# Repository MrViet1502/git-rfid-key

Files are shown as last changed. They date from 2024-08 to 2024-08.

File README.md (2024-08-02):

## Used devices:
- Arduino pro mini 3v3
- MFRC522 and Cards
- Button config
- Button Power
- Buzzer
- USB UART
  
## Wiring connection diagram

- RED and Black big -> 48V
- White of Button (Pin 6)
- Graay of RESET (Pin reset)
- Blue and white big of Relay 
  ### Load code by USB UART
  - Yellow of TX
  - Green of RX
  - Black small of GND
## Link Demo:
https://youtu.be/RNAoaklGJTw

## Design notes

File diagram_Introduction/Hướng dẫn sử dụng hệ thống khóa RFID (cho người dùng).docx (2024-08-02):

Hướng dẫn sử dụng hệ thống khóa RFID

1. Khởi động hệ thống

Nhấn nút R. Màn hình sáng đèn khoảng 1s. Nếu loa kêu 2 tiếng

2. Bật/tắt điều khiển
- Quét thẻ master hoặc thẻ đã đăng ký (lần 1) để bật.
- Quét thẻ master hoặc thẻ đã đăng ký (lần 2) để tắt, đồng thời tắt hệ thống.
3. Tắt hệ thống
- Nhấn nút R khoảng 2s, loa kêu 2 tiếng
- Khi khởi động mà không làm gì hệ thống sẽ cảnh báo người dùng sau 15s loa kêu hồi chuông 5s và sau 30s loa kêu 2 tiếng
- Khi bật điều khiển mà không làm gì sau 3p, loa kêu 2 tiếng
4. Chế độ cài đặt
- Có thể vào chế độ cài đặt trong vòng 15s sau khi khởi động hệ thống. Dùng để thêm thẻ chưa đăng ký, xóa thẻ đã đăng ký, xóa hết tất cả thẻ (trừ thẻ master).
- Cách vào chế độ cài đặt: nhấn nút R 2 lần. Nếu loa kêu 3 tiếng
- Thêm hoặc xóa thẻ: quét thẻ master. Nếu đúng thẻ loa kêu 2 tiếng. Nếu sai thẻ loa kêu 1 tiếng (tiếp tục quét lại cho đến khi đúng). Tiếp tục quét thẻ nếu là thẻ chưa đăng ký (thẻ mới) loa kêu 1 tiếng và thêm thẻ đó, nếu là thẻ đã đăng ký (thẻ cũ) loa kêu 2 tiếng và xóa thẻ đó.
- Xóa hết: quét thẻ master. Nếu đúng thẻ, loa kêu 2 tiếng. Nếu sai thẻ, loa kêu 1 tiếng (tiếp tục quét lại cho đến khi đúng). Nhấn nút R trong 4s loa kêu 3 tiếng và xóa toàn bộ thẻ (trừ master).

Lưu ý: nếu vào chế động cài đặt mà không làm gì thì sẽ tự kết thúc sau 30s.

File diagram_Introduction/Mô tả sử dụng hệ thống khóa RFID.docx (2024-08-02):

Hướng dẫn sử dụng hệ thống khóa RFID

1. Khởi động hệ thống
- Nhấn nút R. Màn hình sáng đèn khoảng 1s. Nếu loa kêu 2 lần mỗi lần 0.4s.
- Khởi động thành công.
2. Chế độ cài đặt
- Có thể vào chế độ cài đặt trong vòng 15s sau khi khởi động hệ thống. Dùng để thêm thẻ chưa đăng ký, xóa thẻ đã đăng ký, xóa hết tất cả thẻ (trừ thẻ master).
- Cách vào chế độ cài đặt: nhấn nút R 2 lần. Nếu loa kêu 3 lần mỗi lần 0.3s.
- Đã vào chế độ cài đặt.
- Thêm hoặc xóa thẻ: quét thẻ master. Nếu đúng thẻ loa kêu 2 lần mỗi lần 0.3s. Nếu sai thẻ loa kêu 1 lần trong 0.3s (tiếp tục cho đến khi đúng). Tiếp tục quét thẻ nếu là thẻ chưa được thêm (thẻ mới) loa kêu 1 lần trong 0.5s và thêm thẻ đó, nếu là thẻ đã đăng ký (thẻ cũ) loa kêu 2 lần mỗi lần 0.5s và xóa thẻ đó.
- Xóa hết: quét thẻ master. Nếu đúng thẻ loa kêu 2 lần mỗi lần 0.3s. Nếu sai thẻ loa kêu 1 lần trong 0.3s (tiếp tục cho đến khi đúng). Nhấn nút R trong 4s loa kêu 3 lần mỗi lần 0.5s và xóa toàn bộ thẻ (trừ master).

Lưu ý: nếu vào chế động cài đặt mà không làm gì thì sẽ tự kết thúc sau 30s.

3. Bật/tắt điều khiển
- Quét thẻ master hoặc thẻ đã đăng ký (lần 1) để bật.
- Quét thẻ master hoặc thẻ đã đăng ký (lần 2) để tắt, đồng thời tắt hệ thống.
4. Tắt hệ thống
- Nhấn nút R khoảng 2s, loa kêu 2 lần mỗi lần 0.4s
- Khi khởi động mà không làm gì hệ thống sẽ cảnh báo người dùng sau 15s loa kêu hồi chuông 5s và sau 30s loa kêu 2 lần mỗi lần 0.4s.
- Khi bật điều khiển mà không làm gì sau 3p, loa kêu 2 lần mỗi lần 0.4s.

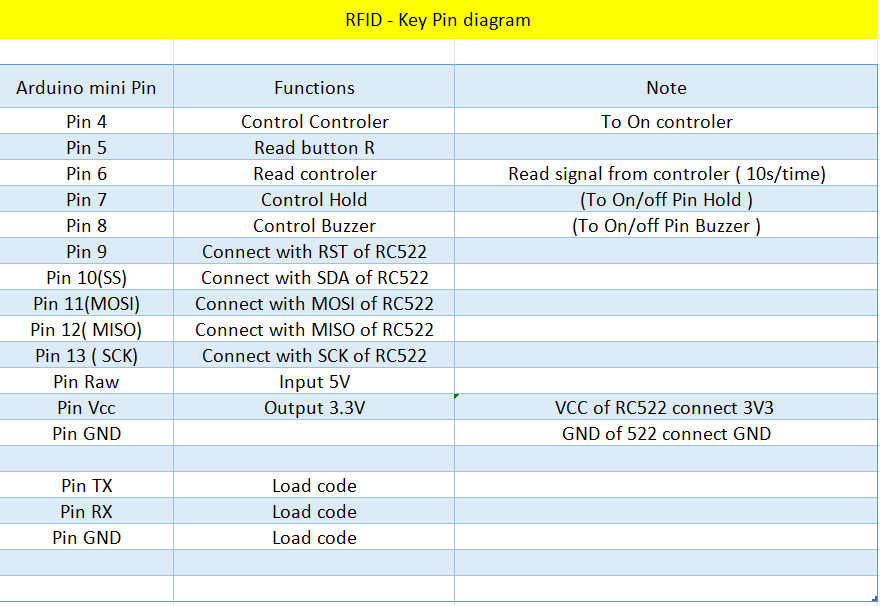
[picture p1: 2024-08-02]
diagram_Introduction/RFID-Key Pin Diagram.png

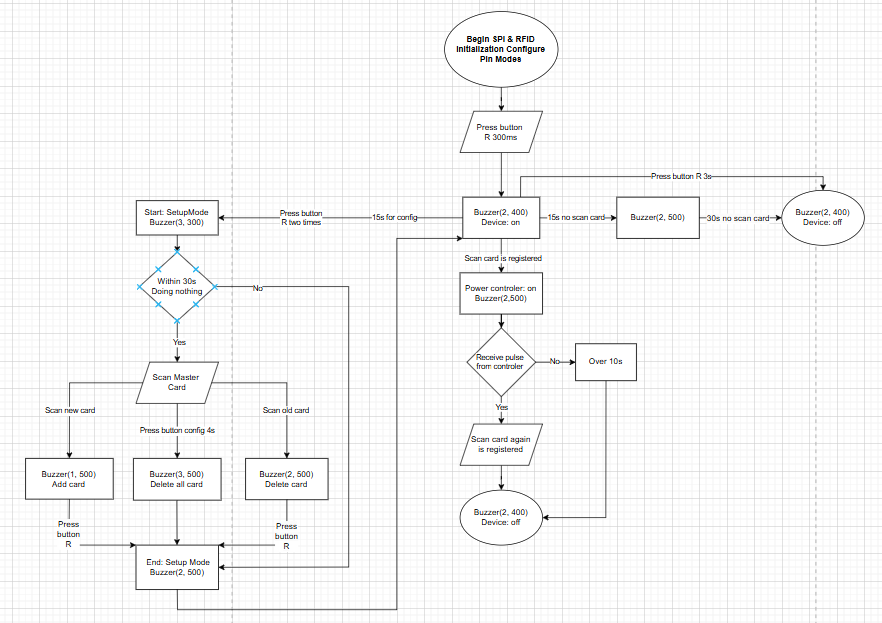
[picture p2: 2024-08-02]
diagram_Introduction/main_flowchart.png

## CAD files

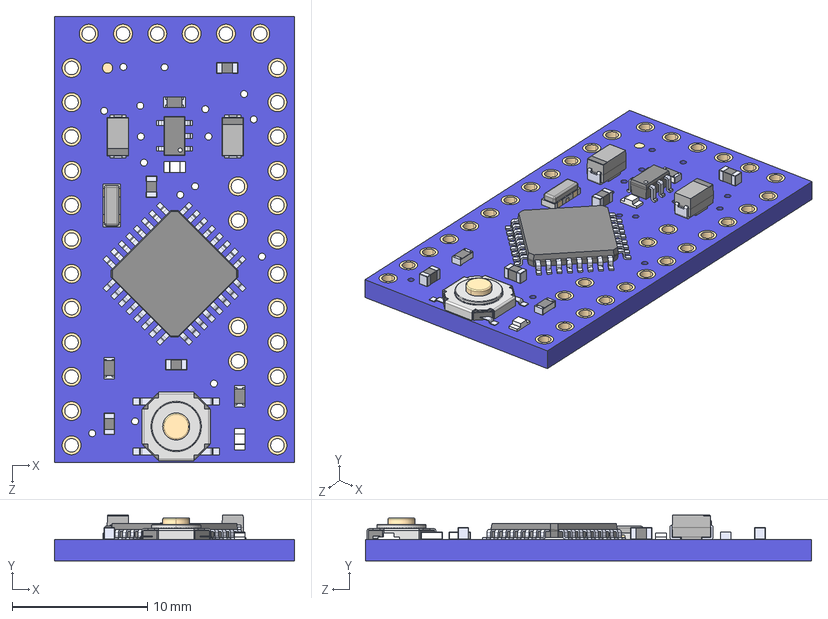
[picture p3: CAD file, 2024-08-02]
Hardware/power/3D/Arduino Pro Mini--3DModel-STEP-510211.STEP
17.8 x 3.37 x 33.0 mm
Arduino Pro Mini_Board
SMD-ALT01
ATMEGA328_ATMEGA168
RESONATOR1_1
CAP_POL1206 x 2
V_REG_LDOSMD
RESISTOR0603-RES x 3
CAP0603-CAP x 4

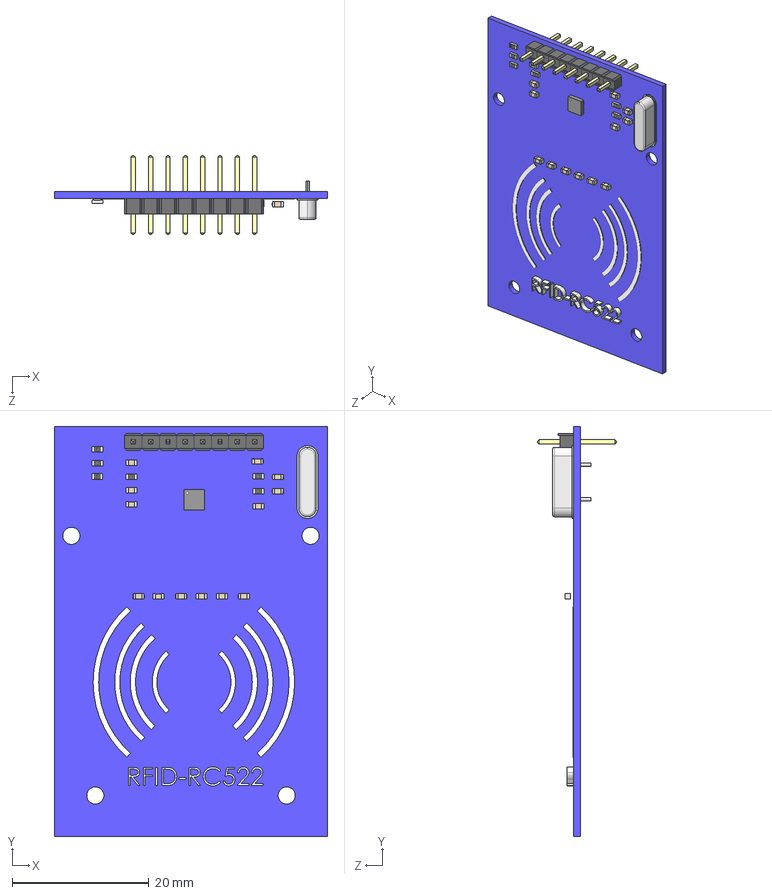
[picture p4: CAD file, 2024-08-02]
Hardware/RFID/3D/RFID.STEP
40.0 x 60.0 x 11.5 mm
User Library-S-PWSON-N12
User Library-Header_Male_8Pin
User Library-SMD Ceramic Capacitors_0603 (1608)_CH x 13

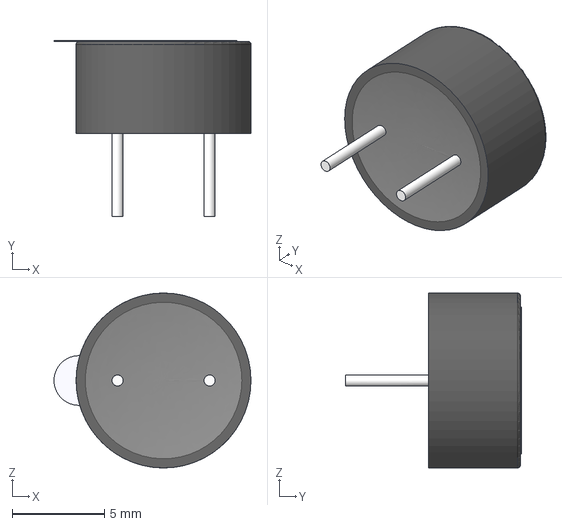
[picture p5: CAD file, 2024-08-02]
Hardware/power/3D/AI-1027-TWT-3V-R--3DModel-STEP-461651.STEP
10.7 x 9.55 x 9.50 mm

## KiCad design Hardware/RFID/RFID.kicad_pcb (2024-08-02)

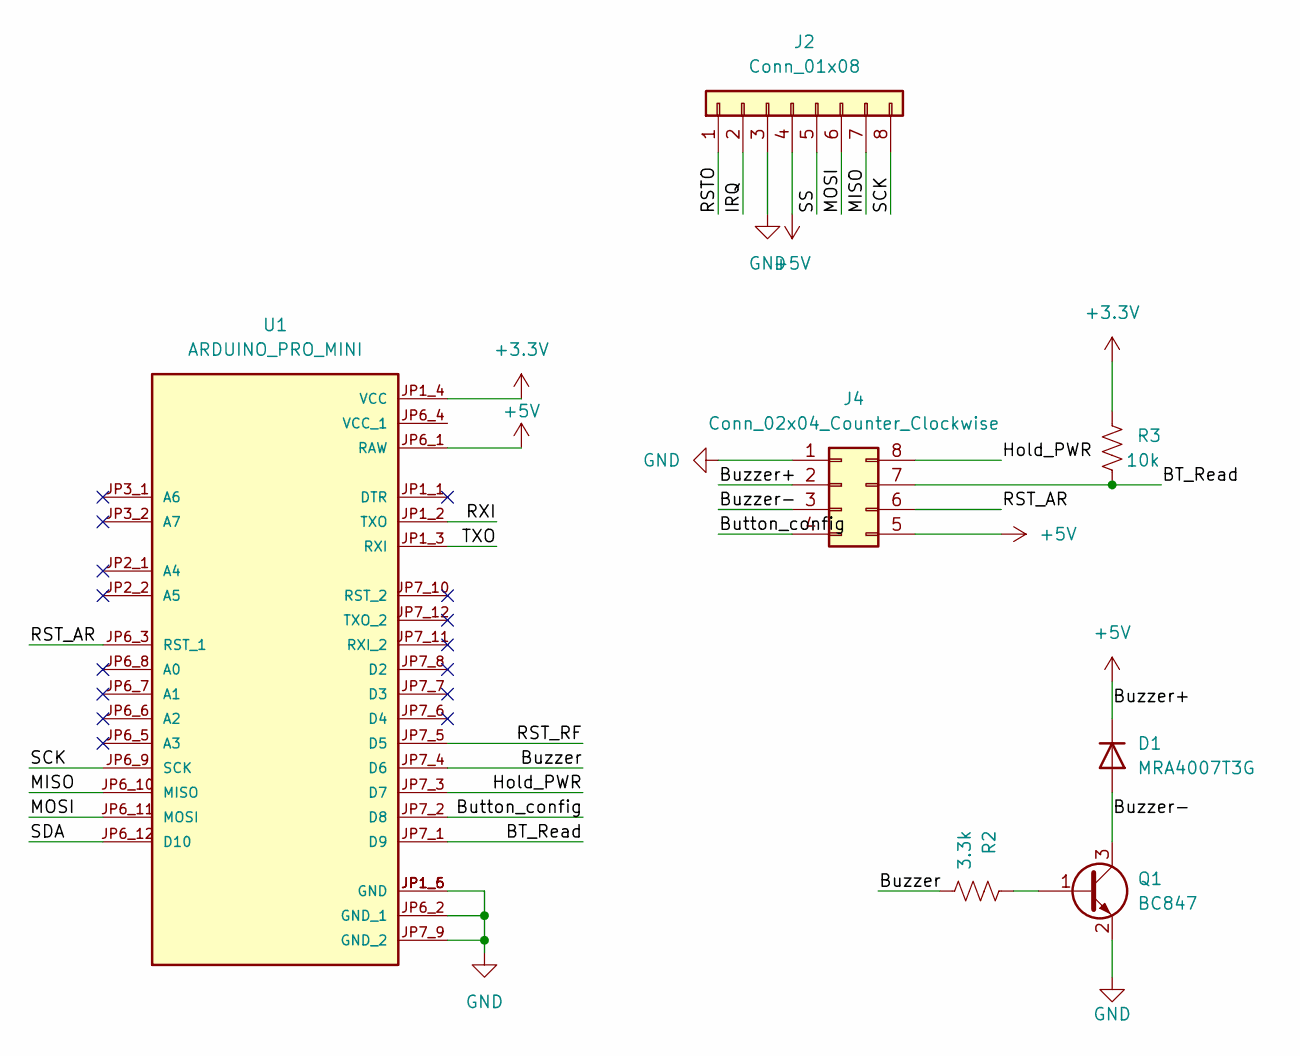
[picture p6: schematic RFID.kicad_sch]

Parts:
D1: MRA4007T3G; D_SMA
J2: Conn_01x08; PinHeader_1x08_P2.54mm_Vertical
J4: Conn_02x04_Counter_Clockwise; PinHeader_2x04_P2.00mm_Vertical
Q1: BC847; SOT-23
R2: 3.3k; R_0603_1608Metric
R3: 10k; R_0603_1608Metric
U1: ARDUINO_PRO_MINI; MODULE_ARDUINO_PRO_MINI; PARTREV N/A

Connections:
+3.3V: R3.1, U1.JP1_4 (VCC)
+5V: D1.1 (K), J2.4, J4.2, J4.5, U1.JP6_1 (RAW)
/BT_Read: J4.7, R3.2, U1.JP7_1 (D9)
/Button_config: J4.4, U1.JP7_2 (D8)
/Buzzer: R2.1, U1.JP7_4 (D6)
/Buzzer-: D1.2 (A), J4.3, Q1.3 (C)
/Hold_PWR: J4.8, U1.JP7_3 (D7)
/IRQ: J2.2
/MISO: J2.7, U1.JP6_10 (MISO)
/MOSI: J2.6, U1.JP6_11 (MOSI)
/RSTO: J2.1
/RST_AR: J4.6, U1.JP6_3 (RST_1)
/RST_RF: U1.JP7_5 (D5)
/RXI: U1.JP1_2 (TXO)
/SCK: J2.8, U1.JP6_9 (SCK)
/SDA: U1.JP6_12 (D10)
/SS: J2.5
/TXO: U1.JP1_3 (RXI)
GND: J2.3, J4.1, Q1.2 (E), U1.JP1_5 (GND), U1.JP1_6 (GND), U1.JP6_2 (GND_1), U1.JP7_9 (GND_2)
unnamed: Q1.1 (B), R2.2

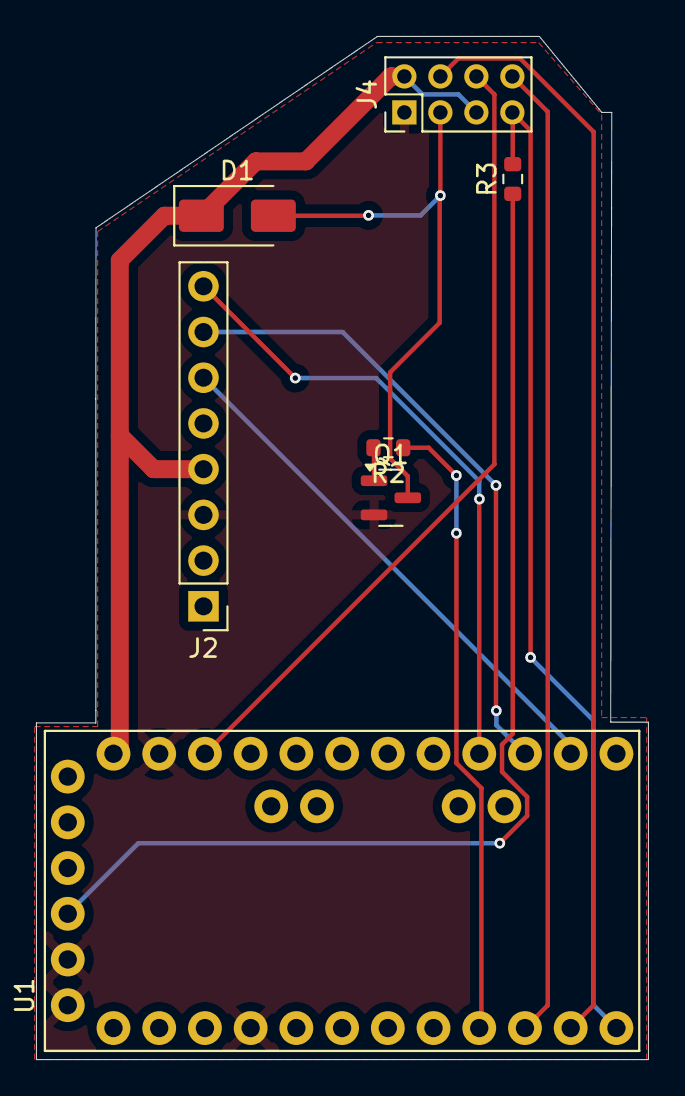
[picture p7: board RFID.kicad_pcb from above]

Board: 2 copper layers, 34.0 x 56.8 mm, 7 parts (0 on the bottom side), 13 nets.

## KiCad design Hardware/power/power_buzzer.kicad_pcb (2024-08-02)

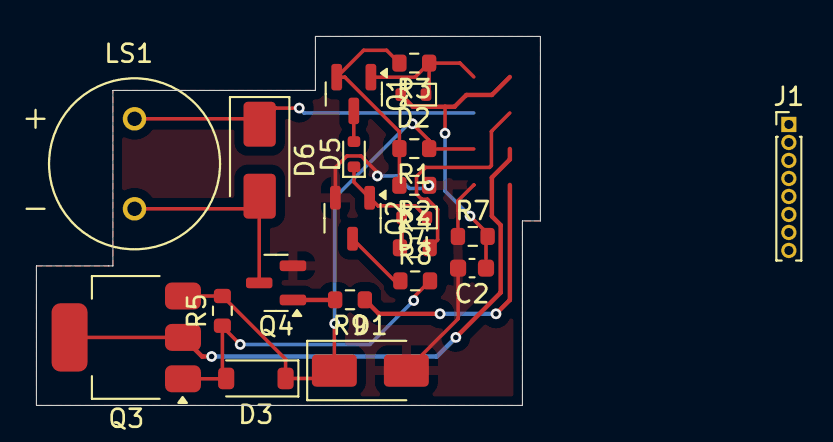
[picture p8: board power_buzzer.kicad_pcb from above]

Board: 2 copper layers, 28.0 x 20.5 mm, 21 parts (0 on the bottom side), 15 nets.

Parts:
C2: 100n; C_0603_1608Metric
D1: SMAJ60A-E3/5A; D_SMA
D2, D4, D5: SBR0220T5-7; D_SOD-523
D3: MMSZ5246BQ-13-F; D_SOD-123
D6: MRA4007T3G; D_SMA
J1: Conn_01x08; PinHeader_1x08_P1.00mm_Vertical
LS1: AI-1027-TWT-3V-R; XDCR_AI-1027-TWT-3V-R
Q1: IRLML6402TRPBF; SOT-23
Q2: BSS123-7-F; SOT-23-3
Q3: DMP10H400SE-13; SOT-223-3_TabPin2
Q4: BC847; SOT-23
R1: 39k; R_0603_1608Metric
R2: 2.2k; R_0603_1608Metric
R3: 100k; R_0603_1608Metric
R4: 100; R_0603_1608Metric
R5: 1M; R_0603_1608Metric
R7: 10k; R_0603_1608Metric
R8: 2.2M; R_0603_1608Metric
R9: 3.3k; R_0603_1608Metric

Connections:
/+5V: D6.1 (K), LS1.P
/BT_PWR: D2.1 (K), J1.2, Q1.1 (G), R3.1
/BT_Read: C2.1, D2.2 (A), J1.1, R7.2
/Hold_PWR: J1.3, R4.2
/KEY_PWR: J1.4, J1.5, Q3.2 (D)
/V_BAT+: D1.1 (K), D3.1 (K), J1.6, Q3.3 (S), R1.1, R5.2
GND: C2.2, D1.2 (A), J1.7, J1.8, Q2.2 (S), Q4.2 (E), R2.1, R7.1
unnamed: D3.2 (A), Q3.1 (G), R5.1, R8.2
unnamed: D4.2 (A), R4.1
unnamed: D4.1 (K), D5.1 (K), Q2.1 (G)
unnamed: D5.2 (A), Q1.3 (D)
unnamed: D6.2 (A), LS1.N, Q4.3 (C)
unnamed: Q1.2 (S), R1.2, R2.2, R3.2
unnamed: Q2.3 (D), R8.1
unnamed: Q4.1 (B), R9.2

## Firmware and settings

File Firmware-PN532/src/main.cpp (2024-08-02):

#include "global.h"

// String tagId = "None";
// byte nuidPICC[4];
void setup()
{
  Serial.begin(9600);
  nfc.begin();
  // nfc.SAMconfig();
  //  SPI.begin();
  //  nfc.setPassiveActivationRetries(0x02);
  //  mfrc522.PCD_Init();
  Serial.println("Lectura del UID");

  pinMode(LED_BUILTIN, OUTPUT);              // led for test arduino mini
  pinMode(HOLD_PIN, OUTPUT);                 // hold power
  pinMode(BUZZER_PIN, OUTPUT);               // buzzer
  pinMode(CONTROLER_PIN, OUTPUT);            // power for controler
  pinMode(BUTTON_READ_PIN, INPUT_PULLUP);    // read this button for hold power
  pinMode(READ_CONTROLER_PIN, INPUT_PULLUP); // read from controler
  digitalWrite(HOLD_PIN, LOW);               // hold power: off
  digitalWrite(BUZZER_PIN, LOW);             // buzzer: off
  digitalWrite(CONTROLER_PIN, LOW);          // power: off for controler
  loadCardsFromEEPROM();
}

void loop()
{
  pressButtonRForOpenAndClose(); // check button R for open

  switch (currentState)
  {
  case IDLE_STATE:
    if (isHoldForOpen())
    {
      currentState = WAIT_FOR_CARD;
    }
    break;

  case WAIT_FOR_CARD:
    checkButtonRForSetupMode(); // check button R for setup mode

    if (isSetupModeActive() && !overTime(setupTime, TIME_SETUPMODE))
    {
      currentState = SETUP_MODE;
    }
    else if (readNFC())
    {
      currentState = CARD_SCANNED;
    }

    // off hold if within 30s isSetupMode = false and card has't been scanned
    overTimeOffHold();

    // off hold if within 10s controler don't send signal
    // overTimerControlerOffHold();
    break;

  case CARD_SCANNED:
    // Serial.print("Card UID:");
    // for (byte i = 0; i < mfrc522.uid.size; i++)
    // {
    //   Serial.print(mfrc522.uid.uidByte[i] < 0x10 ? " 0" : " ");
    //   Serial.print(mfrc522.uid.uidByte[i], HEX);
    // }
    // Serial.println();
    // mfrc522.PICC_HaltA();

    if (isCardRegistered(uid))
    {
      if (checkReadControler)
      {
        offHold();
        Serial.print("off hold");
      }
      onControl();
      Serial.print("on hold");
      currentState = IDLE_STATE; // Back to status IDLE_STATE after processing
    }
    else
    {
      currentState = UNAUTHORIZED;
    }
    break;

  case SETUP_MODE:
    handleSetupMode(); // case setup mode
    if (overTime(configTime, TIME_CONFIG_END))
    {
      exitSetupMode(); // case exit setup mode if time out
      currentState = IDLE_STATE;
    }
    break;

  case UNAUTHORIZED:
    // Serial.println("Unauthorized card.");
    currentState = IDLE_STATE; // Back to status IDLE_STATE after processing
    break;
  }
  // delay(2000);
}

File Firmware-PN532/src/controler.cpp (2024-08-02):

#include "global.h"

void onControl()
{
    Serial.println("Power on controler");
    digitalWrite(CONTROLER_PIN, HIGH);
    buzzerBeep(1, 1000);
    checkReadControler = true; // for scan card again when off hold
    holdOffFirstTime = false;  // for on hold
    lastChangeTime = millis(); // time for HB
}

// Read pulse from controler
// if over 10s then off hold
void controlControler()
{
    inputState = digitalRead(READ_CONTROLER_PIN);

    if (inputState != lastInputState)
    {
        lastChangeTime = millis();
        lastInputState = inputState;
        Serial.println("HB");
    }

    if (millis() - lastChangeTime > TIME_NOPULSE)
    {
        // Serial.println("over time for HB");
        offHold();
    }
}
